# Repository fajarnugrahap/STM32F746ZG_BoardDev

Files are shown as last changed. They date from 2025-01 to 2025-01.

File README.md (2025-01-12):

# STM32F746ZG_Minimum-System
There are some embedded features in this minimum system like UART, I2C, CAN Bus, QuadSPI Flash, Ext. SDRAM, SPI for LCD TFT/Oled Support, USB-C and GPIO port                                              
WhatsApp Image 2024-07-21 at 20 56 39_34f741bc

First thing first I set the pinout configuration of STM32F746ZG by using CubeMx tools in STM32CubeIDE
                                                          
I'm using KiCadV6+ to design this minimum system. There is some additional component to support some peripheral/bus. You can check the component library folder.
f746zg
f746zg(1)
f746zg(3)

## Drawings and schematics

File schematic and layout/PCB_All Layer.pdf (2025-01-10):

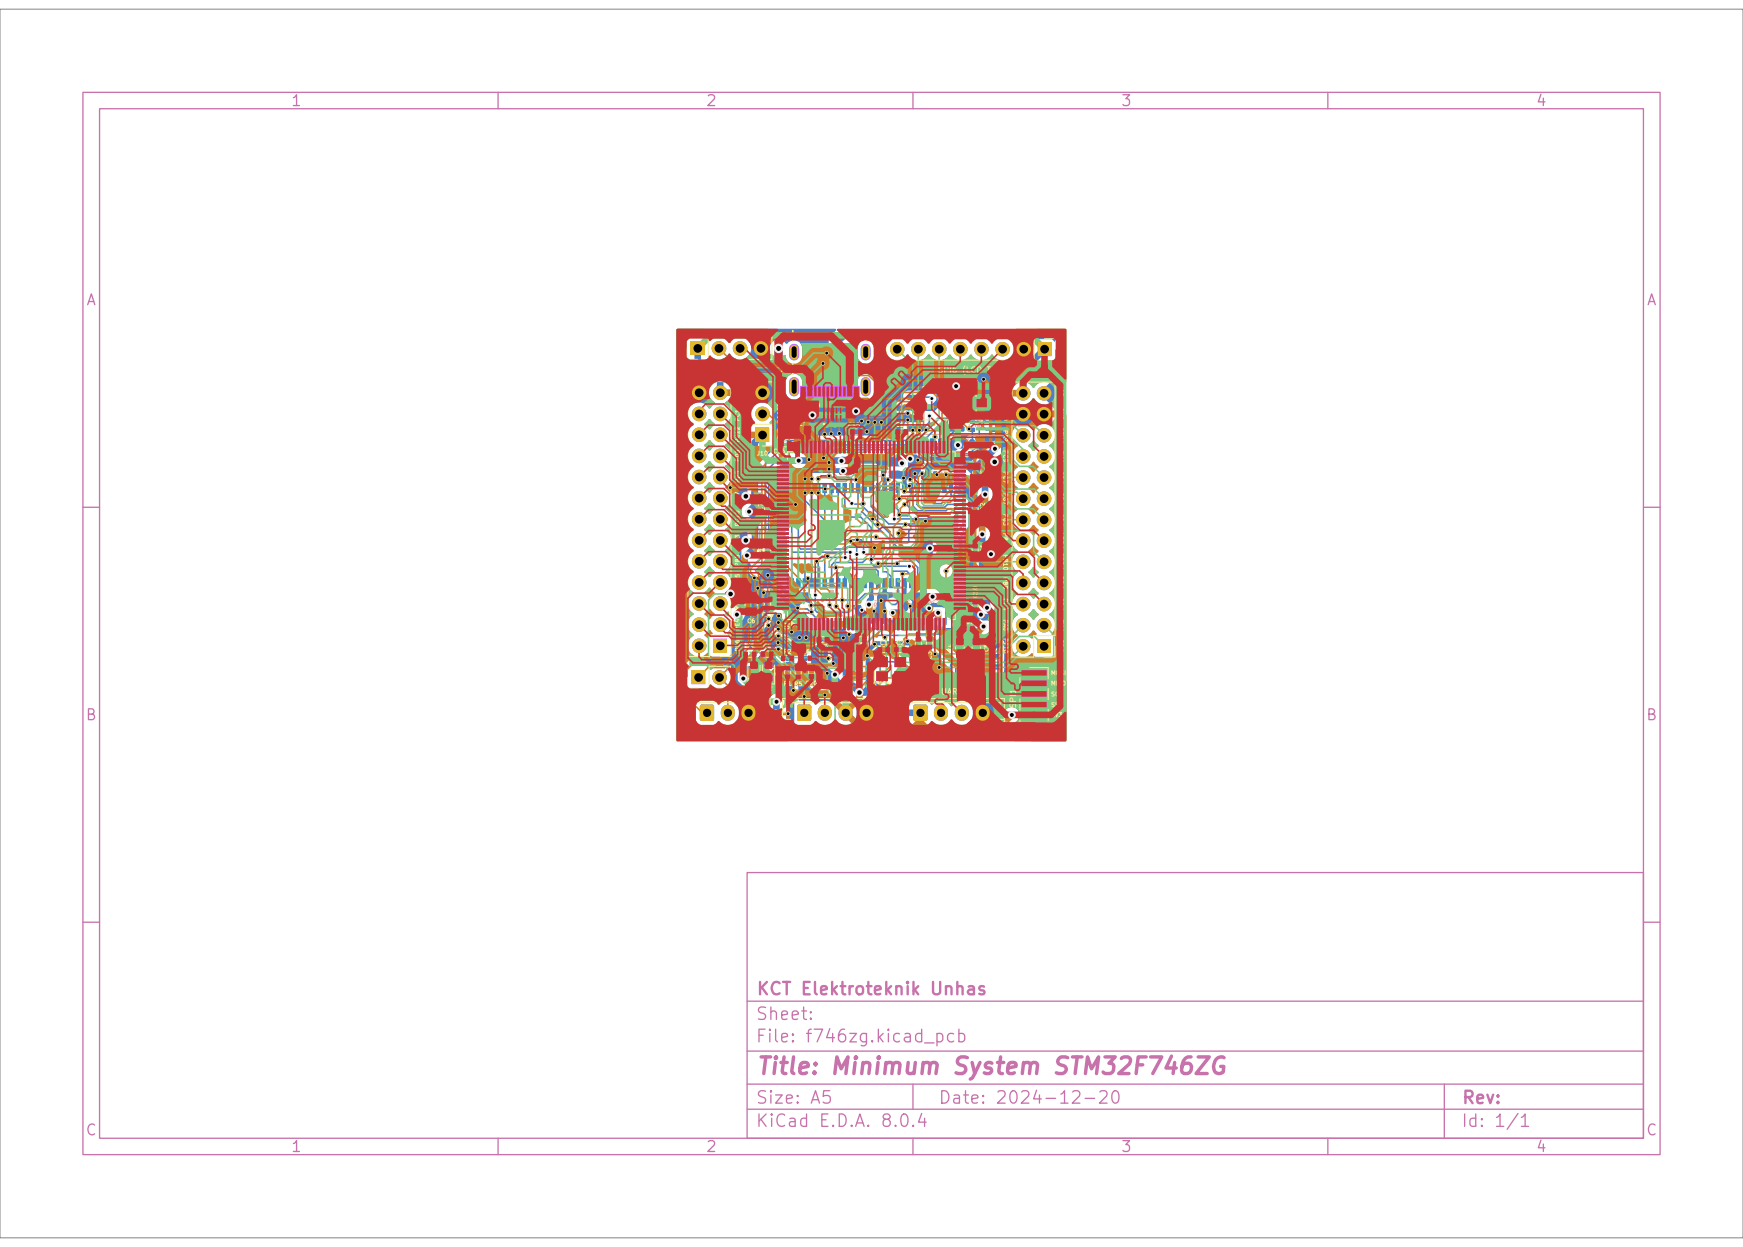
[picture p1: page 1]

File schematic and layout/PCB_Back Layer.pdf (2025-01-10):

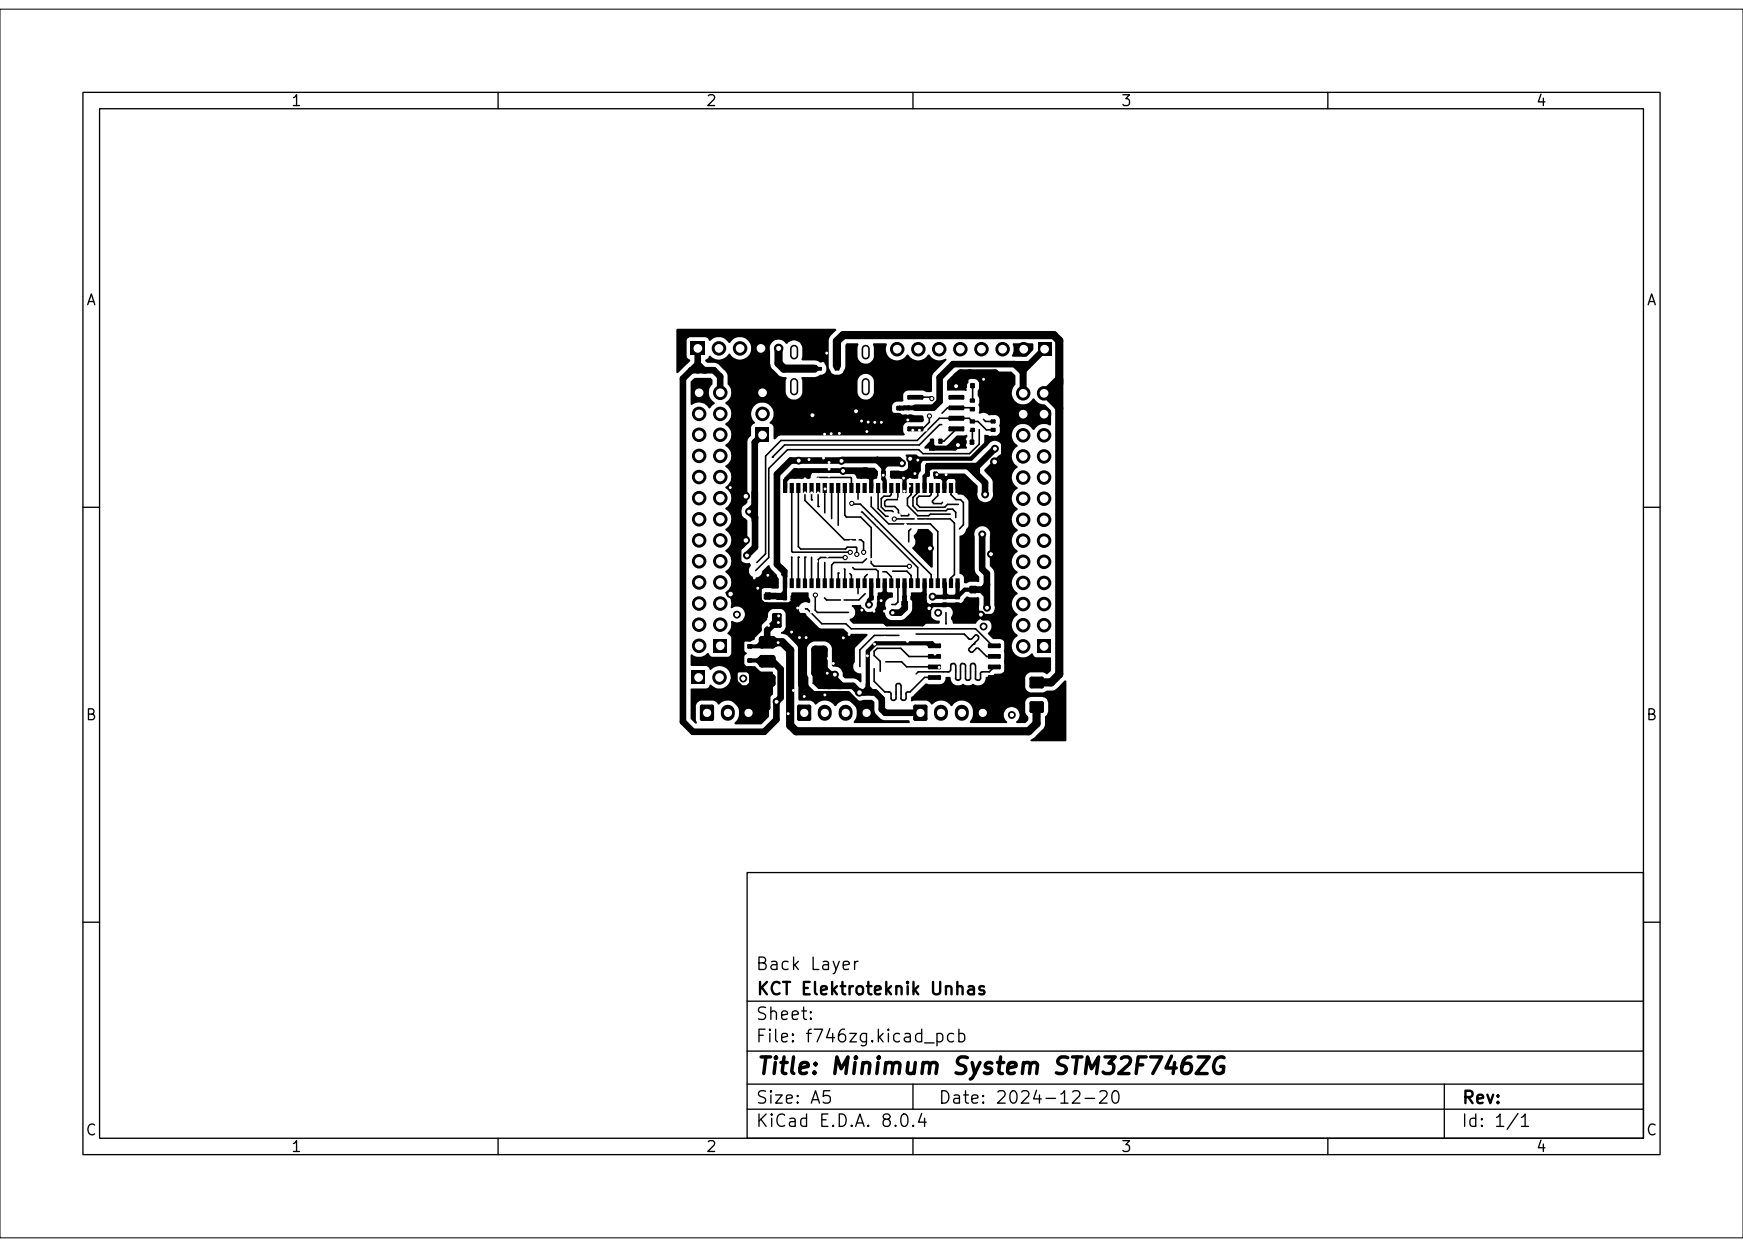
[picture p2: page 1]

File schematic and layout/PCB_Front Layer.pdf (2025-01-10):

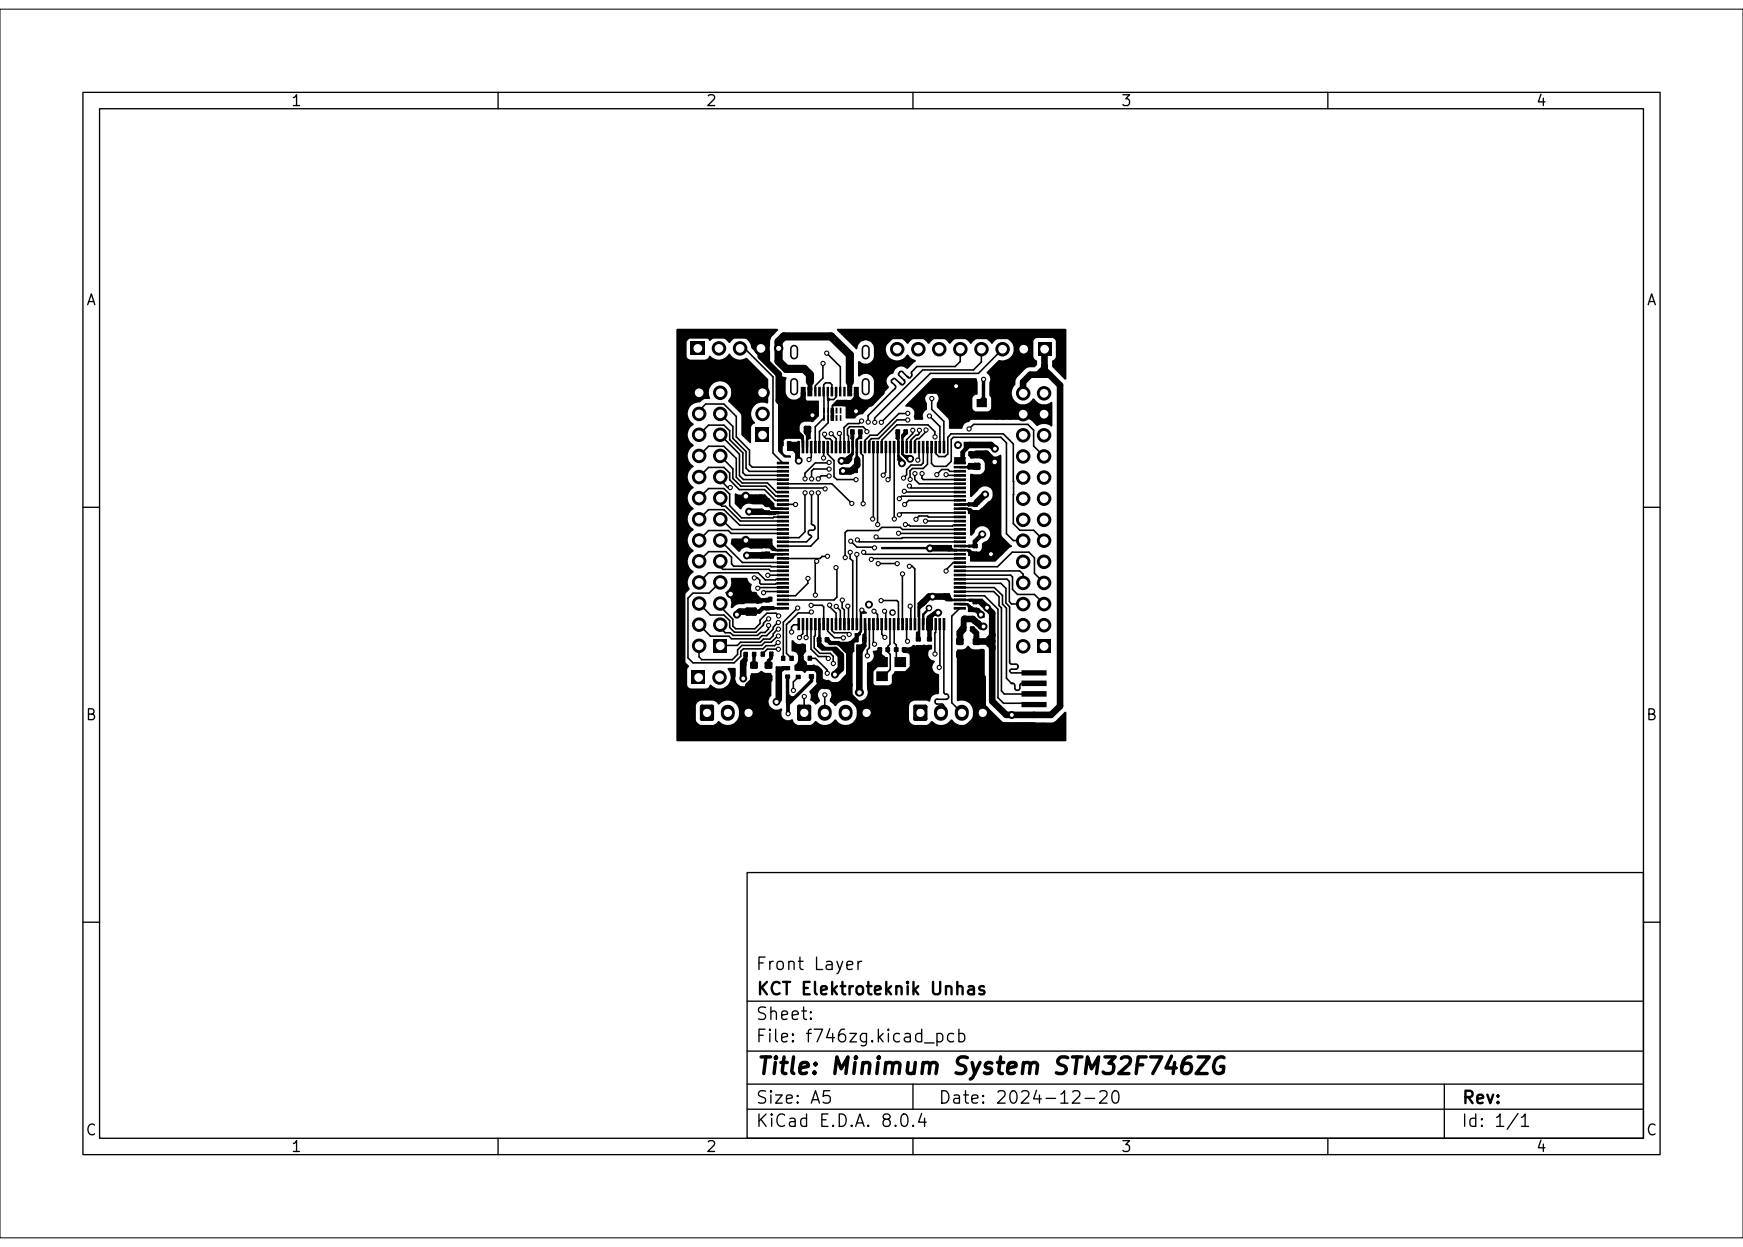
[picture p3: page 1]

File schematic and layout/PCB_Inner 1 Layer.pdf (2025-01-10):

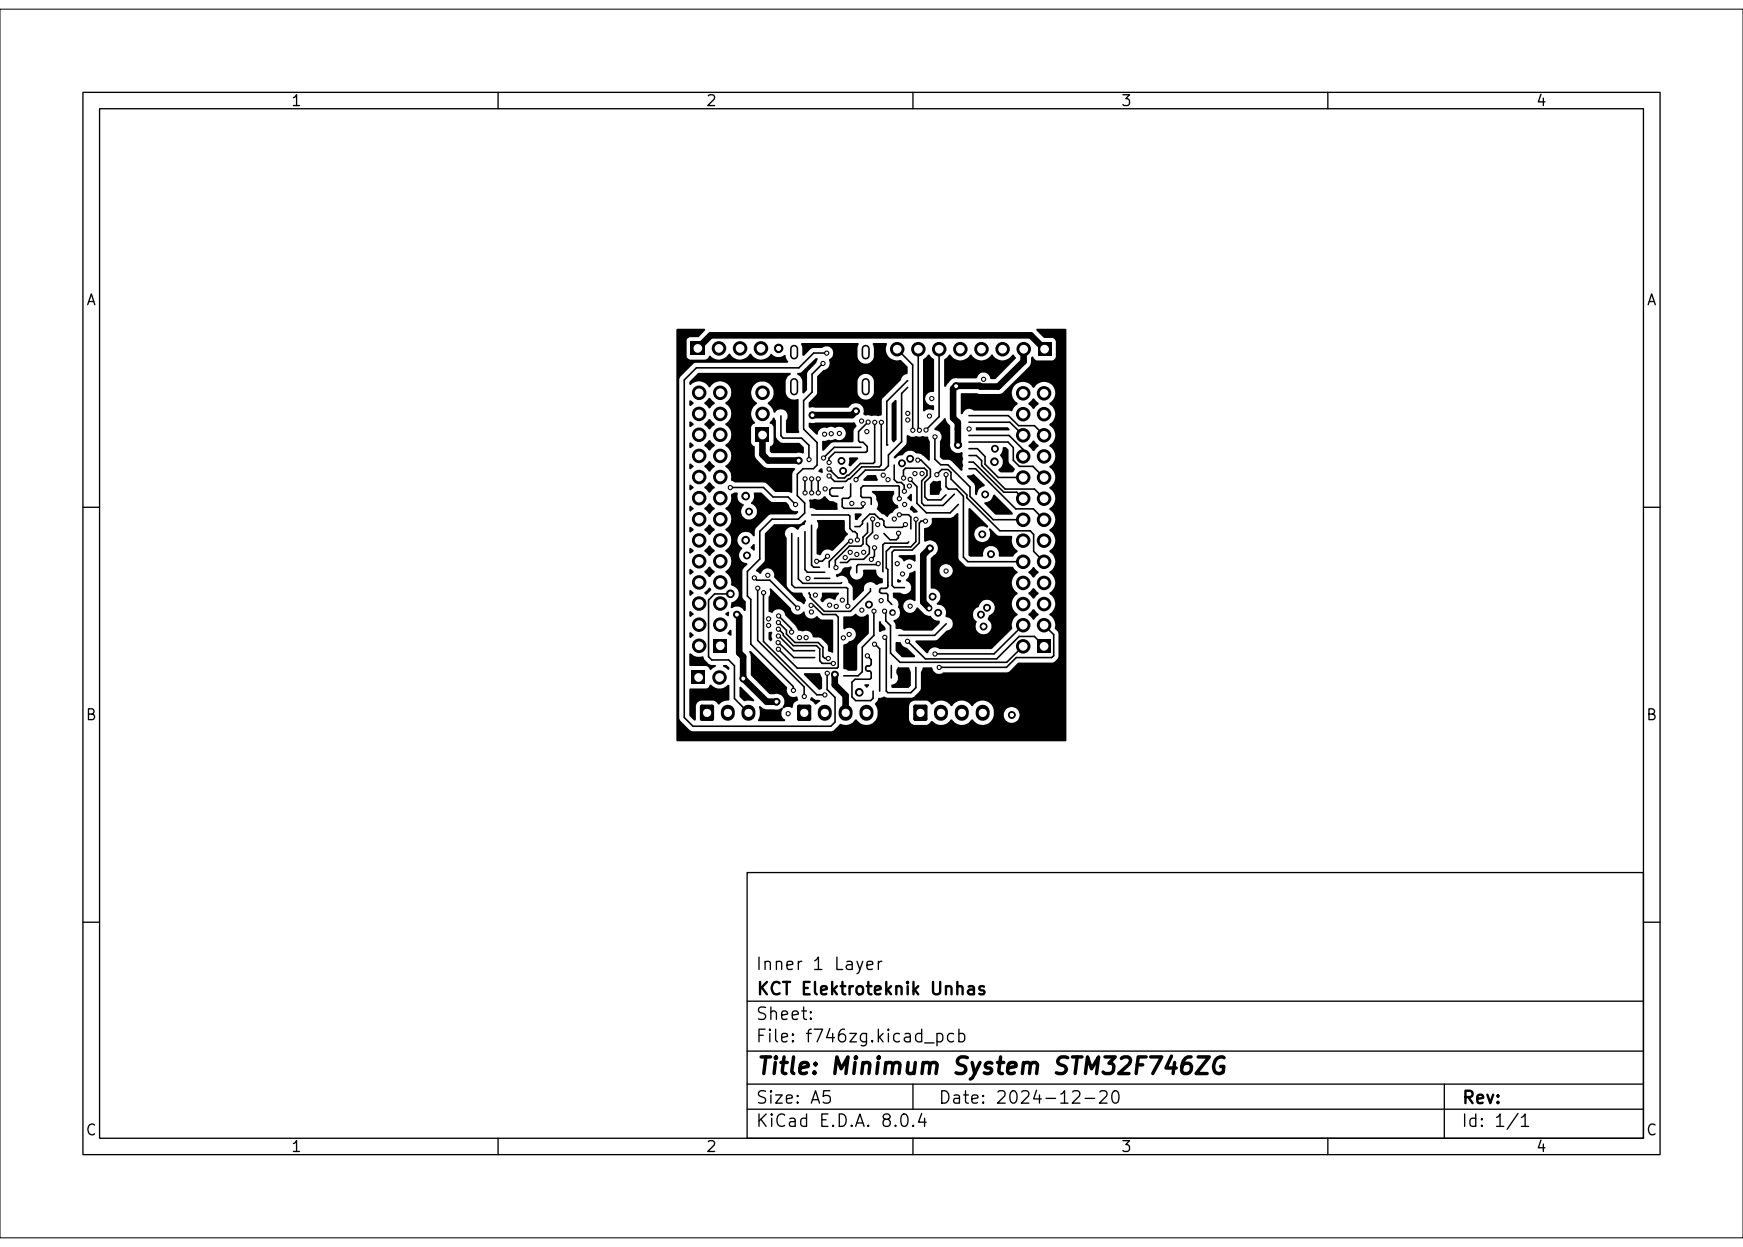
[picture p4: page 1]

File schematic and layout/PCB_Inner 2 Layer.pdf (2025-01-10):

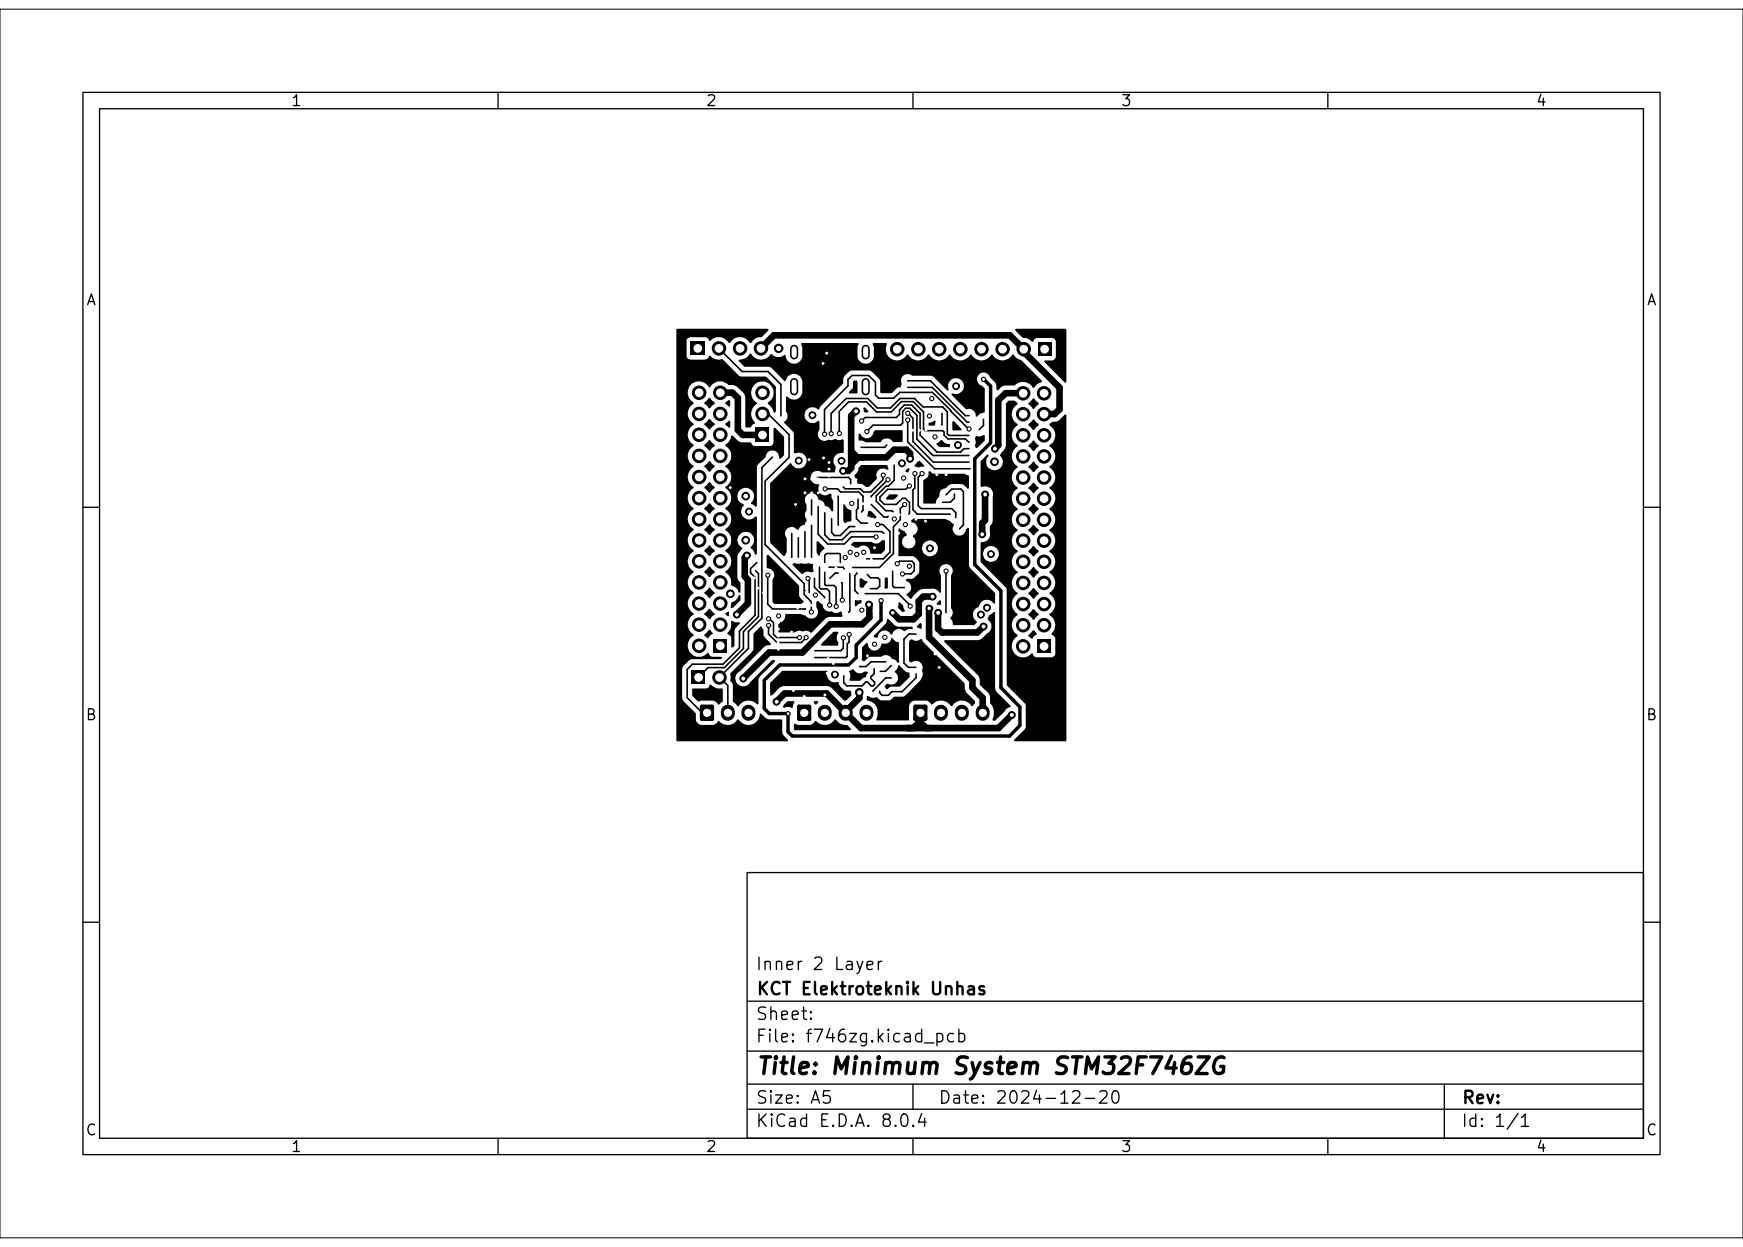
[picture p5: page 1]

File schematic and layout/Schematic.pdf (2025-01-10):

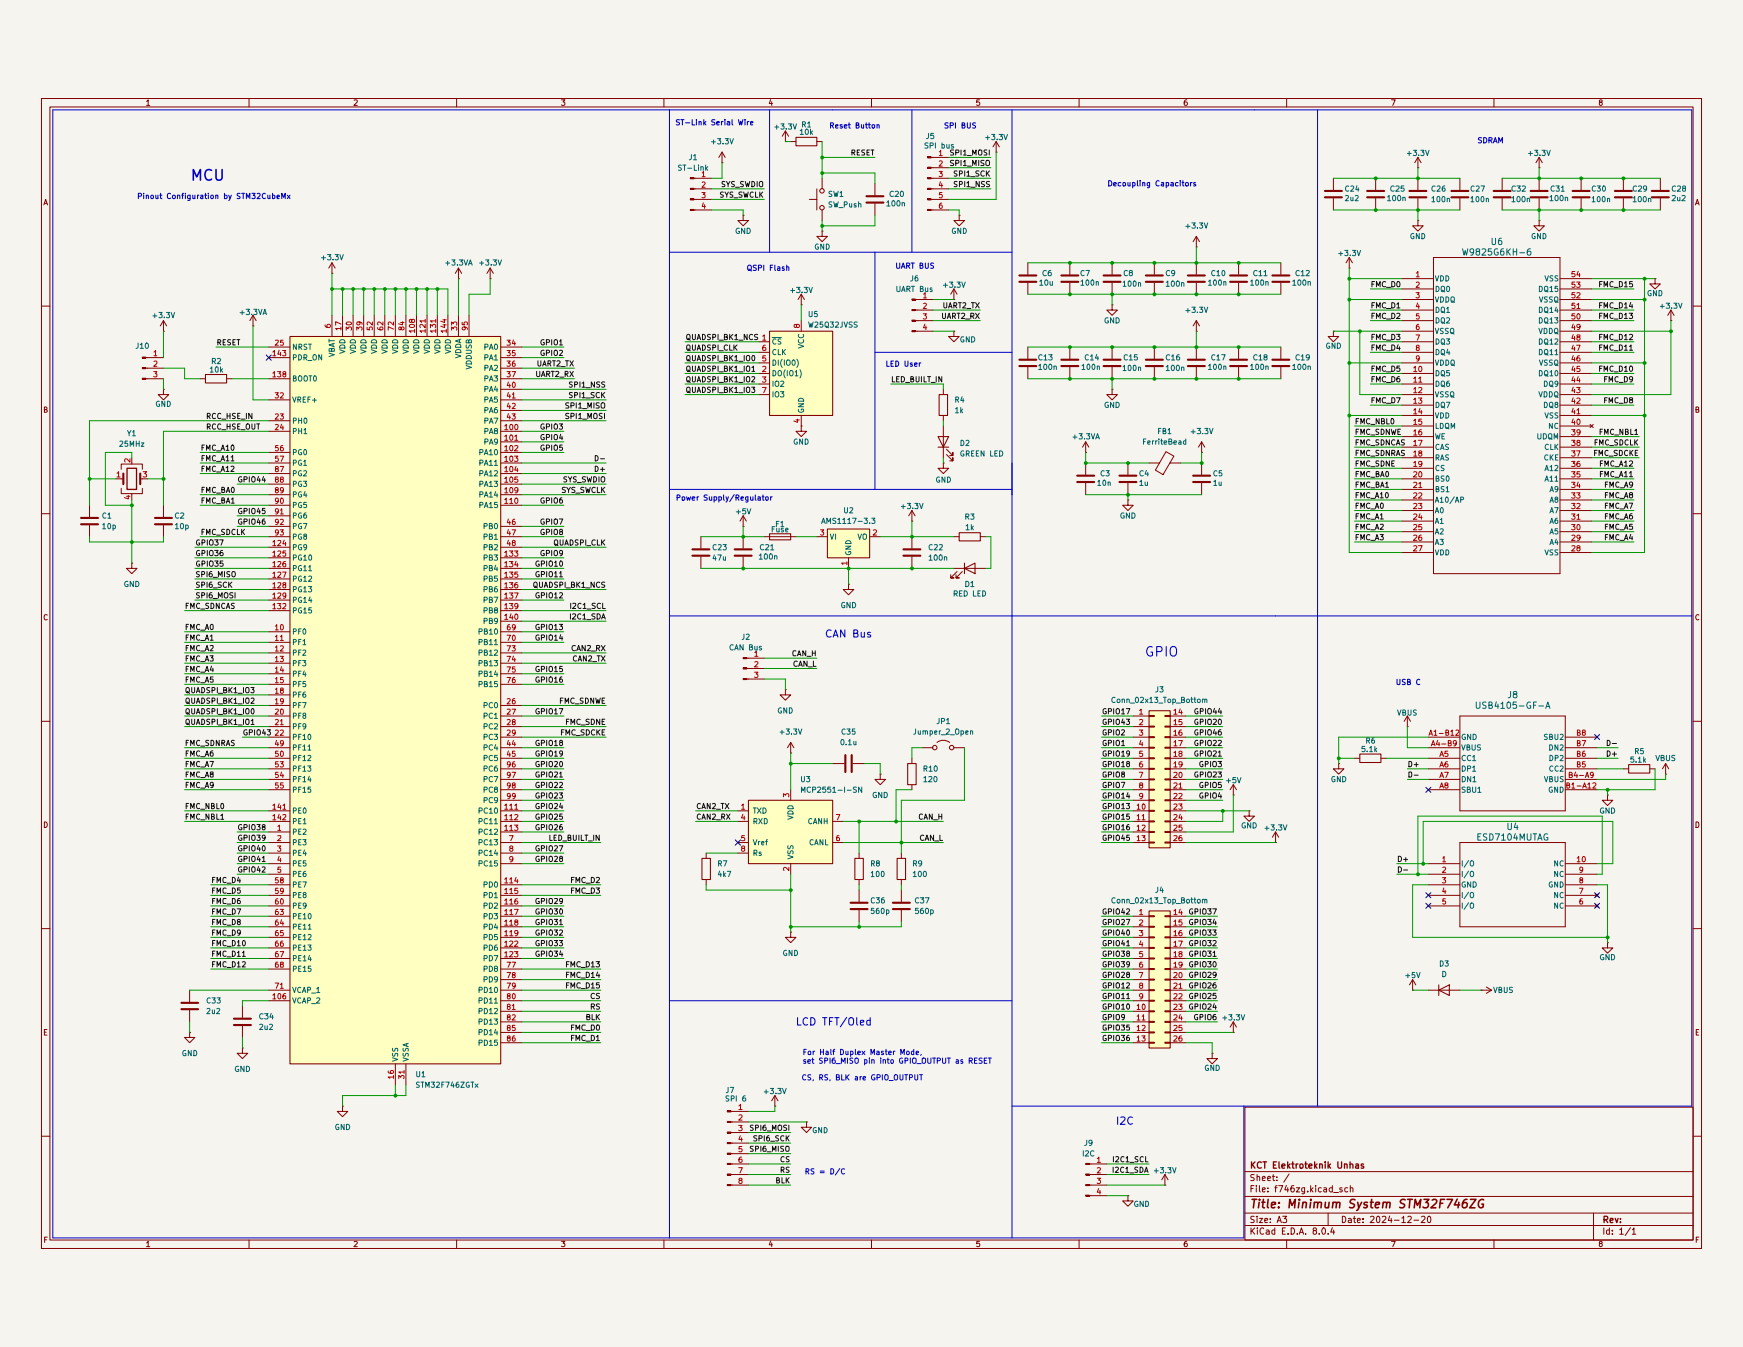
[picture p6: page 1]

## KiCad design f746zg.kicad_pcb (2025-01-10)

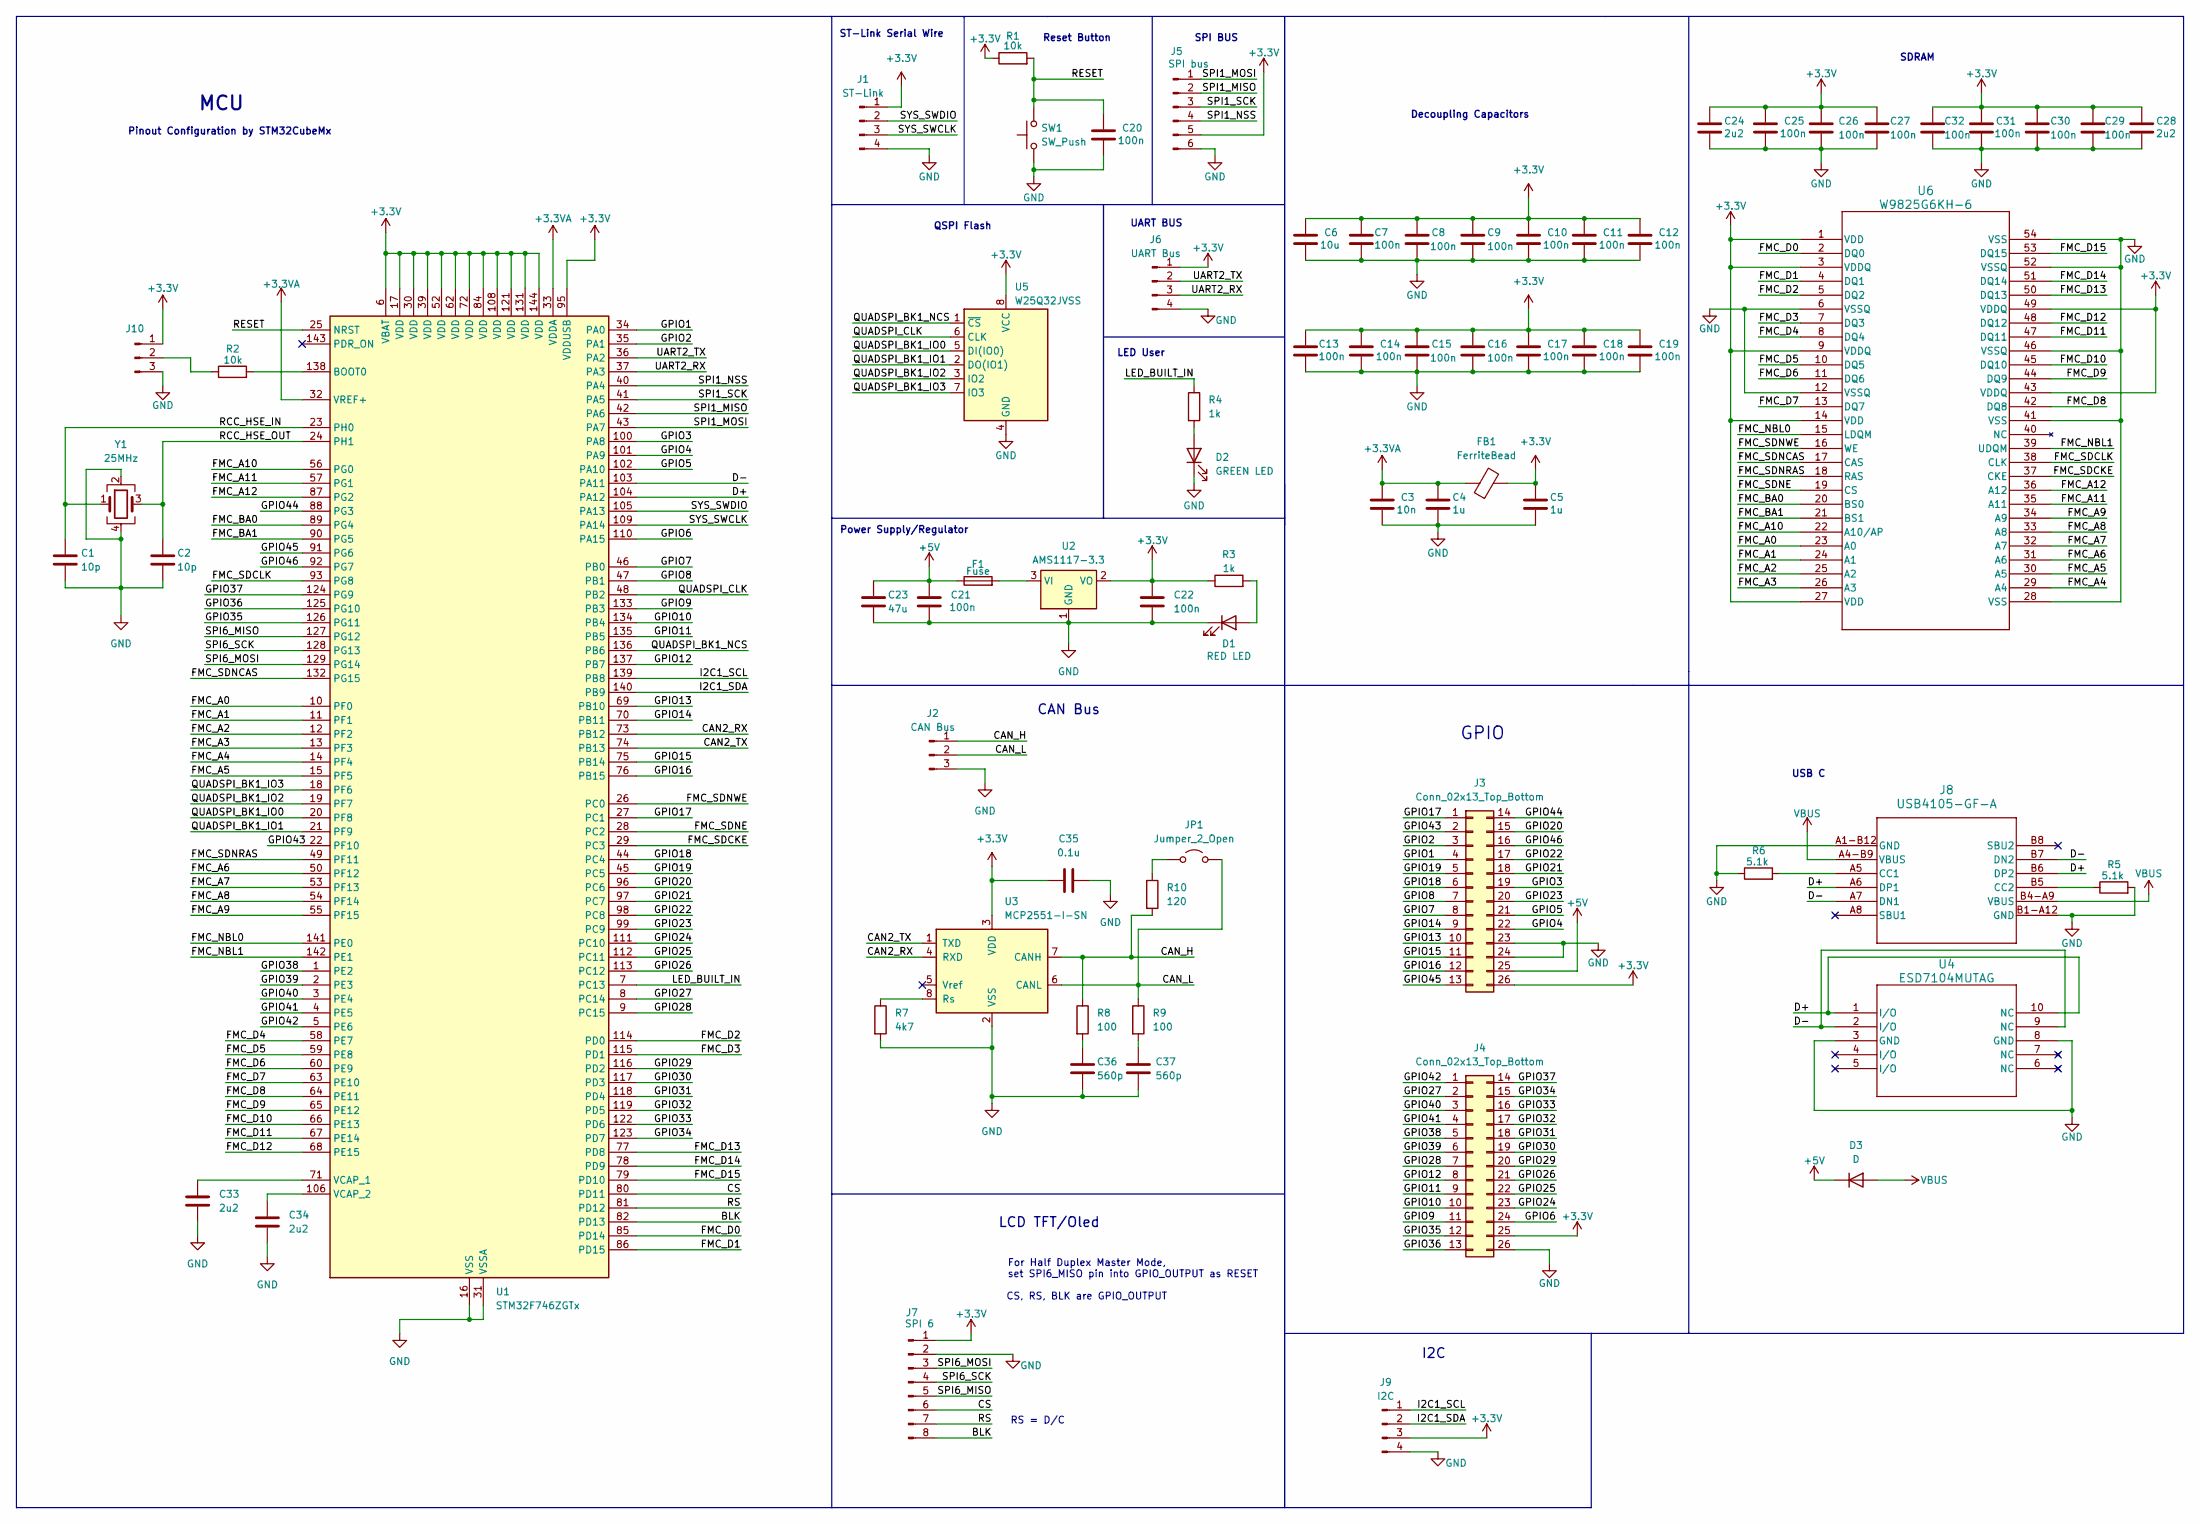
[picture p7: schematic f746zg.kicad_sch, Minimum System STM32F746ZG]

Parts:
C1, C2: 10p; C_0402_1005Metric
C3: 10n; C_0402_1005Metric
C4, C5: 1u; C_0603_1608Metric
C6: 10u; C_0805_2012Metric
C7, C8, C9, C10, C11, C12, C13, C14, C15, C16, C17, C18, C19, C20, C21, C22, C25, C26, C27, C29, C30, C31, C32: 100n; C_0402_1005Metric
C23: 47u; C_1206_3216Metric
C24, C28, C33, C34: 2u2; C_0603_1608Metric
C35: 0.1u; C_0402_1005Metric
C36, C37: 560p; C_0402_1005Metric
D1: RED LED; LED_0603_1608Metric
D2: GREEN LED; LED_0603_1608Metric
D3: D; D_SOD-323
F1: Fuse; Fuse_1206_3216Metric_Pad1.42x1.75mm_HandSolder
FB1: FerriteBead; L_0402_1005Metric
J1: ST-Link; PinHeader_1x04_P2.54mm_Vertical
J2: CAN Bus; JST_EH_B3B-EH-A_1x03_P2.50mm_Vertical
J3, J4: Conn_02x13_Top_Bottom; PinHeader_2x13_P2.54mm_Vertical
J5: SPI bus; PinHeader_1x06_P1.27mm_Vertical_SMD_Pin1Left
J6: UART Bus; JST_EH_B4B-EH-A_1x04_P2.50mm_Vertical
J7: SPI 6; PinHeader_1x08_P2.54mm_Vertical
J8: USB4105-GF-A; GCT_USB4105-GF-A
J9: I2C; JST_EH_B4B-EH-A_1x04_P2.50mm_Vertical
J10: Conn_01x03_Pin; PinHeader_1x03_P2.54mm_Vertical
JP1: Jumper_2_Open; PinHeader_1x02_P2.54mm_Vertical
R1, R2: 10k; R_0402_1005Metric
R3, R4: 1k; R_0402_1005Metric
R5, R6: 5.1k; R_0402_1005Metric
R7: 4k7; R_0402_1005Metric
R8, R9: 100; R_0402_1005Metric
R10: 120; R_0402_1005Metric
SW1: SW_Push; SW_Tactile_SPST_NO_Straight_CK_PTS636Sx25SMTRLFS
U1: STM32F746ZGTx; LQFP-144_20x20mm_P0.5mm
U2: AMS1117-3.3; SOT-223-3_TabPin2
U3: MCP2551-I-SN; SOIC-8_3.9x4.9mm_P1.27mm
U4: ESD7104MUTAG; UDFN10_ONS
U5: W25Q32JVSS; SOIC-8_5.23x5.23mm_P1.27mm
U6: W9825G6KH-6; SMT_5G6KH-6_WIN
Y1: 25MHz; Crystal_SMD_3225-4Pin_3.2x2.5mm

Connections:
+3.3V: C5.1, C6.1, C7.1, C8.1, C9.1, C10.1, C11.1, C12.1, C13.1, C14.1, C15.1, C16.1, C17.1, C18.1, C19.1, C22.1, C24.1, C25.1, C26.2, C27.2, C28.1, C29.2, C30.2, C31.1, C32.2, C35.1, FB1.2, J1.1, J3.26, J4.25, J5.5, J6.1, J7.1, J9.3, J10.1, R1.1, R3.1, U1.6 (VBAT), U1.17 (VDD), U1.30 (VDD), U1.39 (VDD), U1.52 (VDD), U1.62 (VDD), U1.72 (VDD), U1.84 (VDD), U1.95 (VDDUSB), U1.108 (VDD), U1.121 (VDD), U1.131 (VDD), U1.144 (VDD), U2.2 (VO), U3.3 (VDD), U5.8 (VCC), U6.1 (VDD), U6.3 (VDDQ), U6.9 (VDDQ), U6.14 (VDD), U6.27 (VDD), U6.43 (VDDQ), U6.49 (VDDQ)
+3.3VA: C3.1, C4.1, FB1.1, U1.32 (VREF+), U1.33 (VDDA)
/BLK: J7.8, U1.82 (PD13)
/CAN2_RX: U1.73 (PB12), U3.4 (RXD)
/CAN2_TX: U1.74 (PB13), U3.1 (TXD)
/CAN_H: J2.1, R8.1, R10.2, U3.7 (CANH)
/CAN_L: J2.2, JP1.2 (B), R9.1, U3.6 (CANL)
/CS: J7.6, U1.80 (PD11)
/D+: J8.A6 (DP1), J8.B6 (DP2), U1.104 (PA12), U4.1 (I/O), U4.10 (NC)
/D-: J8.A7 (DN1), J8.B7 (DN2), U1.103 (PA11), U4.2 (I/O), U4.9 (NC)
/FMC_A0: U1.10 (PF0), U6.23 (A0)
/FMC_A1: U1.11 (PF1), U6.24 (A1)
/FMC_A2: U1.12 (PF2), U6.25 (A2)
/FMC_A3: U1.13 (PF3), U6.26 (A3)
/FMC_A4: U1.14 (PF4), U6.29 (A4)
/FMC_A5: U1.15 (PF5), U6.30 (A5)
/FMC_A6: U1.50 (PF12), U6.31 (A6)
/FMC_A7: U1.53 (PF13), U6.32 (A7)
/FMC_A8: U1.54 (PF14), U6.33 (A8)
/FMC_A9: U1.55 (PF15), U6.34 (A9)
/FMC_A10: U1.56 (PG0), U6.22 (A10/AP)
/FMC_A11: U1.57 (PG1), U6.35 (A11)
/FMC_A12: U1.87 (PG2), U6.36 (A12)
/FMC_BA0: U1.89 (PG4), U6.20 (BS0)
/FMC_BA1: U1.90 (PG5), U6.21 (BS1)
/FMC_D0: U1.85 (PD14), U6.2 (DQ0)
/FMC_D1: U1.86 (PD15), U6.4 (DQ1)
/FMC_D2: U1.114 (PD0), U6.5 (DQ2)
/FMC_D3: U1.115 (PD1), U6.7 (DQ3)
/FMC_D4: U1.58 (PE7), U6.8 (DQ4)
/FMC_D5: U1.59 (PE8), U6.10 (DQ5)
/FMC_D6: U1.60 (PE9), U6.11 (DQ6)
/FMC_D7: U1.63 (PE10), U6.13 (DQ7)
/FMC_D8: U1.64 (PE11), U6.42 (DQ8)
/FMC_D9: U1.65 (PE12), U6.44 (DQ9)
/FMC_D10: U1.66 (PE13), U6.45 (DQ10)
/FMC_D11: U1.67 (PE14), U6.47 (DQ11)
/FMC_D12: U1.68 (PE15), U6.48 (DQ12)
/FMC_D13: U1.77 (PD8), U6.50 (DQ13)
/FMC_D14: U1.78 (PD9), U6.51 (DQ14)
/FMC_D15: U1.79 (PD10), U6.53 (DQ15)
/FMC_NBL0: U1.141 (PE0), U6.15 (LDQM)
/FMC_NBL1: U1.142 (PE1), U6.39 (UDQM)
/FMC_SDCKE: U1.29 (PC3), U6.37 (CKE)
/FMC_SDCLK: U1.93 (PG8), U6.38 (CLK)
/FMC_SDNCAS: U1.132 (PG15), U6.17 (CAS)
/FMC_SDNE: U1.28 (PC2), U6.19 (CS)
/FMC_SDNRAS: U1.49 (PF11), U6.18 (RAS)
/FMC_SDNWE: U1.26 (PC0), U6.16 (WE)
/GPIO1: J3.4, U1.34 (PA0)
/GPIO2: J3.3, U1.35 (PA1)
/GPIO3: J3.19, U1.100 (PA8)
/GPIO4: J3.22, U1.101 (PA9)
/GPIO5: J3.21, U1.102 (PA10)
/GPIO6: J4.24, U1.110 (PA15)
/GPIO7: J3.8, U1.46 (PB0)
/GPIO8: J3.7, U1.47 (PB1)
/GPIO9: J4.11, U1.133 (PB3)
/GPIO10: J4.10, U1.134 (PB4)
/GPIO11: J4.9, U1.135 (PB5)
/GPIO12: J4.8, U1.137 (PB7)
/GPIO13: J3.10, U1.69 (PB10)
/GPIO14: J3.9, U1.70 (PB11)
/GPIO15: J3.11, U1.75 (PB14)
/GPIO16: J3.12, U1.76 (PB15)
/GPIO17: J3.1, U1.27 (PC1)
/GPIO18: J3.6, U1.44 (PC4)
/GPIO19: J3.5, U1.45 (PC5)
/GPIO20: J3.15, U1.96 (PC6)
/GPIO21: J3.18, U1.97 (PC7)
/GPIO22: J3.17, U1.98 (PC8)
/GPIO23: J3.20, U1.99 (PC9)
/GPIO24: J4.23, U1.111 (PC10)
/GPIO25: J4.22, U1.112 (PC11)
/GPIO26: J4.21, U1.113 (PC12)
/GPIO27: J4.2, U1.8 (PC14)
/GPIO28: J4.7, U1.9 (PC15)
/GPIO29: J4.20, U1.116 (PD2)
/GPIO30: J4.19, U1.117 (PD3)
/GPIO31: J4.18, U1.118 (PD4)
/GPIO32: J4.17, U1.119 (PD5)
/GPIO33: J4.16, U1.122 (PD6)
/GPIO34: J4.15, U1.123 (PD7)
/GPIO35: J4.12, U1.126 (PG11)
/GPIO36: J4.13, U1.125 (PG10)
/GPIO37: J4.14, U1.124 (PG9)
/GPIO38: J4.5, U1.1 (PE2)
/GPIO39: J4.6, U1.2 (PE3)
/GPIO40: J4.3, U1.3 (PE4)
/GPIO41: J4.4, U1.4 (PE5)
/GPIO42: J4.1, U1.5 (PE6)
/GPIO43: J3.2, U1.22 (PF10)
/GPIO44: J3.14, U1.88 (PG3)
/GPIO45: J3.13, U1.91 (PG6)
/GPIO46: J3.16, U1.92 (PG7)
/I2C1_SCL: J9.1, U1.139 (PB8)
/I2C1_SDA: J9.2, U1.140 (PB9)
/LED_BUILT_IN: R4.1, U1.7 (PC13)
/QUADSPI_BK1_IO0: U1.20 (PF8), U5.5 (DI(IO0))
/QUADSPI_BK1_IO1: U1.21 (PF9), U5.2 (DO(IO1))
/QUADSPI_BK1_IO2: U1.19 (PF7), U5.3 (IO2)
/QUADSPI_BK1_IO3: U1.18 (PF6), U5.7 (IO3)
/QUADSPI_BK1_NCS: U1.136 (PB6), U5.1 (~CS)
/QUADSPI_CLK: U1.48 (PB2), U5.6 (CLK)
/RCC_HSE_IN: C1.1, U1.23 (PH0), Y1.1
/RCC_HSE_OUT: C2.1, U1.24 (PH1), Y1.3
/RESET: C20.1, R1.2, SW1.2, U1.25 (NRST)
/RS: J7.7, U1.81 (PD12)
/SPI1_MISO: J5.2, U1.42 (PA6)
/SPI1_MOSI: J5.1, U1.43 (PA7)
/SPI1_NSS: J5.4, U1.40 (PA4)
/SPI1_SCK: J5.3, U1.41 (PA5)
/SPI6_MISO: J7.5, U1.127 (PG12)
/SPI6_MOSI: J7.3, U1.129 (PG14)
/SPI6_SCK: J7.4, U1.128 (PG13)
/SYS_SWCLK: J1.3, U1.109 (PA14)
/SYS_SWDIO: J1.2, U1.105 (PA13)
/UART2_RX: J6.3, U1.37 (PA3)
/UART2_TX: J6.2, U1.36 (PA2)
GND: C1.2, C2.2, C3.2, C4.2, C5.2, C6.2, C7.2, C8.2, C9.2, C10.2, C11.2, C12.2, C13.2, C14.2, C15.2, C16.2, C17.2, C18.2, C19.2, C20.2, C21.2, C22.2, C23.2, C24.2, C25.2, C26.1, C27.1, C28.2, C29.1, C30.1, C31.2, C32.1, C33.2, C34.2, C35.2, C36.1, C37.1, D1.1 (K), D2.1 (K), J1.4, J2.3, J3.23, J3.24, J4.26, J5.6, J6.4, J7.2, J8.A1-B12 (GND), J8.A1_B12, J8.B1-A12 (GND), J8.B1_A12, J9.4, J10.3, R5.2, R6.1, R7.2, SW1.1, U1.16 (VSS), U1.31 (VSSA), U1.38 (VSS), U1.51 (VSS), U1.61 (VSS), U1.83 (VSS), U1.94 (VSS), U1.107 (VSS), U1.120 (VSS), U1.130 (VSS), U2.1 (GND), U3.2 (VSS), U4.3 (GND), U4.8 (GND), U5.4 (GND), U6.6 (VSSQ), U6.12 (VSSQ), U6.28 (VSS), U6.41 (VSS), U6.46 (VSSQ), U6.52 (VSSQ), U6.54 (VSS), Y1.2, Y1.4
unnamed: C36.2, R8.2
unnamed: C37.2, R9.2
unnamed: D1.2 (A), R3.2
unnamed: D2.2 (A), R4.2
unnamed: J8.A5 (CC1), R6.2
unnamed: J8.B5 (CC2), R5.1
unnamed: J10.2, R2.1
unnamed: JP1.1 (A), R10.1
unnamed: R2.2, U1.138 (BOOT0)
unnamed: C33.1, U1.71 (VCAP_1)
unnamed: C34.1, U1.106 (VCAP_2)
unnamed: R7.1, U3.8 (Rs)
VBUS: D3.2 (A), J8.A4-B9 (VBUS), J8.A4_B9, J8.B4-A9 (VBUS), J8.B4_A9

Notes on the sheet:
Decoupling Capacitors
QSPI Flash
LED User
SDRAM
UART BUS
RS = D/C
SPI BUS
USB C
CAN Bus
GPIO
Pinout Configuration by STM32CubeMx
For Half Duplex Master Mode, set SPI6_MISO pin into GPIO_OUTPUT as RESET
CS, RS, BLK are GPIO_OUTPUT
ST-Link Serial Wire
Power Supply/Regulator
I2C
Reset Button
LCD TFT/Oled
MCU

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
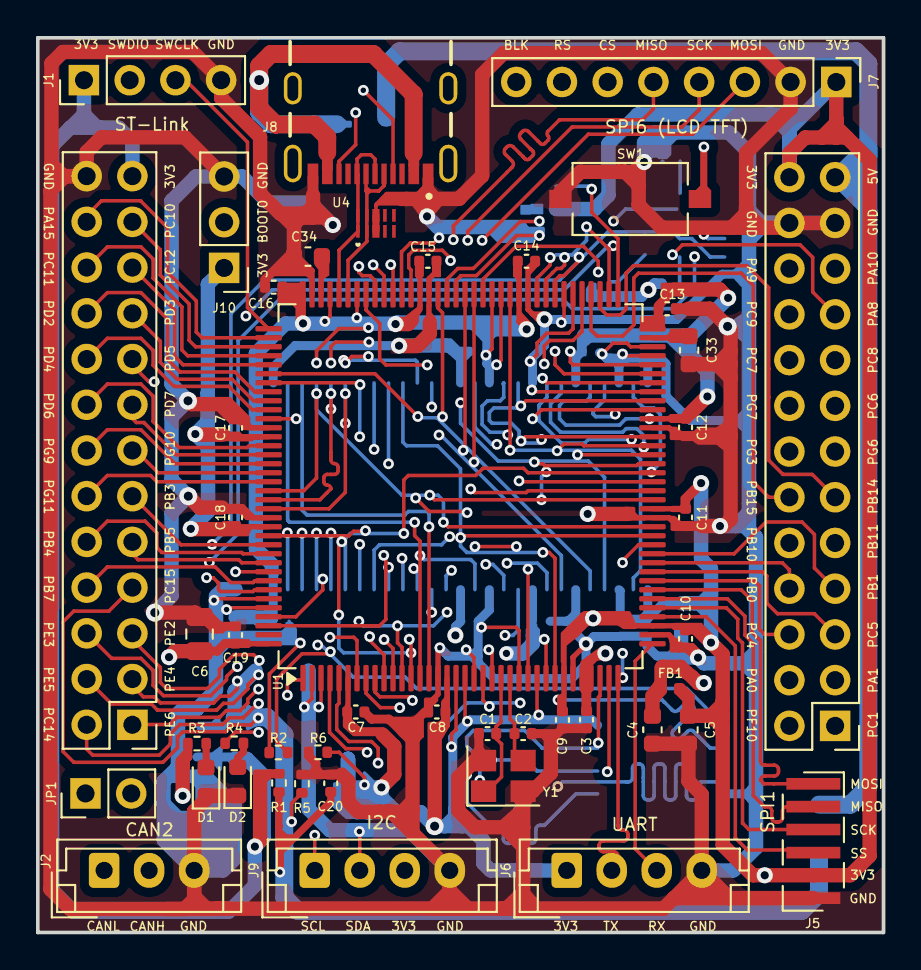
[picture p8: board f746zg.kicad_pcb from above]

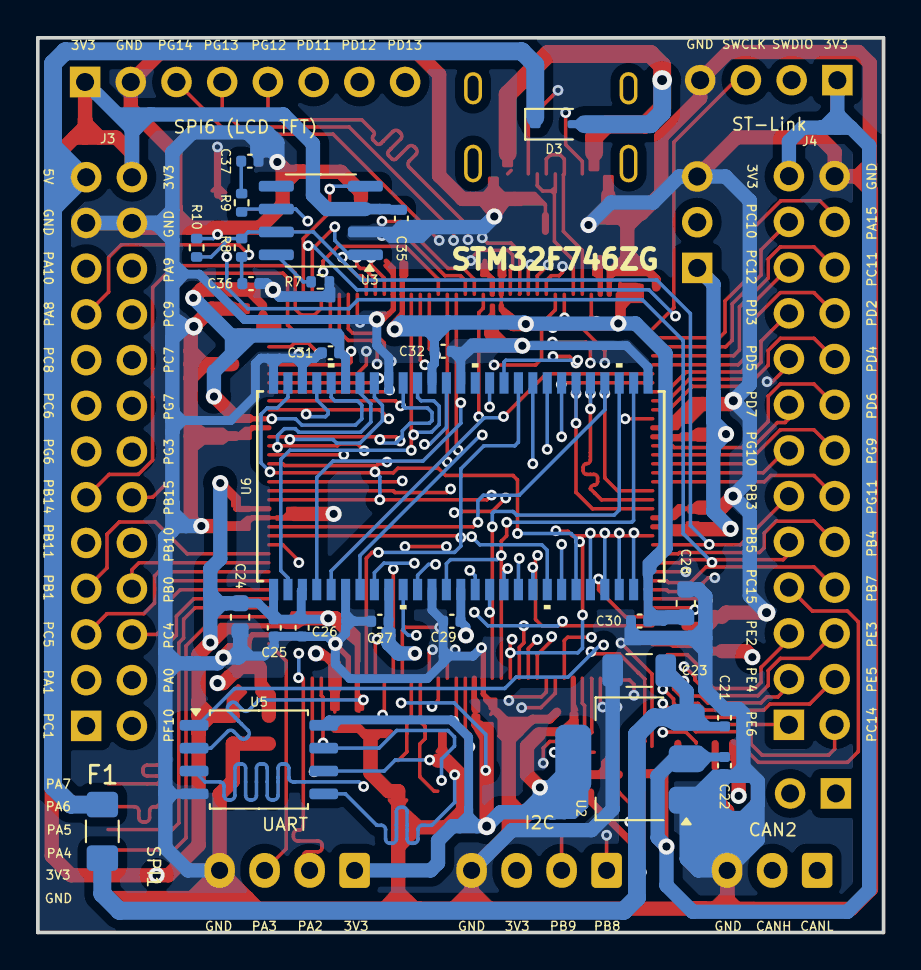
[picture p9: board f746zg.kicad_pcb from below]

Board: 4 copper layers, 47.0 x 49.7 mm, 71 parts (25 on the bottom side), 135 nets.

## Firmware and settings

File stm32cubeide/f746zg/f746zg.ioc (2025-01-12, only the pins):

Mcu.UserName=STM32F746ZGTx
PA0/WKUP.Signal=UART4_TX
PA1.Signal=UART4_RX
PA10.Signal=USB_OTG_FS_ID
PA11.Signal=USB_OTG_FS_DM
PA12.Signal=USB_OTG_FS_DP
PA13.Signal=SYS_JTMS-SWDIO
PA14.Signal=SYS_JTCK-SWCLK
PA4.Signal=SPI1_NSS
PA5.Signal=SPI1_SCK
PA6.Signal=SPI1_MISO
PA8.Signal=USB_OTG_FS_SOF
PA9.Signal=USB_OTG_FS_VBUS
PB12.Signal=CAN2_RX
PB13.Signal=CAN2_TX
PB2.Signal=QUADSPI_CLK
PB5.Signal=SPI1_MOSI
PB6.Signal=QUADSPI_BK1_NCS
PB7.Signal=I2C1_SDA
PB8.Signal=I2C1_SCL
PC0.Signal=FMC_SDNWE
PC13.Signal=GPIO_Output
PC2.Signal=FMC_SDNE0
PC3.Signal=FMC_SDCKE0
PD0.Signal=FMC_D2_DA2
PD1.Signal=FMC_D3_DA3
PD10.Signal=FMC_D15_DA15
PD14.Signal=FMC_D0_DA0
PD15.Signal=FMC_D1_DA1
PD8.Signal=FMC_D13_DA13
PD9.Signal=FMC_D14_DA14
PE0.Signal=FMC_NBL0
PE1.Signal=FMC_NBL1
PE10.Signal=FMC_D7_DA7
PE11.Signal=FMC_D8_DA8
PE12.Signal=FMC_D9_DA9
PE13.Signal=FMC_D10_DA10
PE14.Signal=FMC_D11_DA11
PE15.Signal=FMC_D12_DA12
PE7.Signal=FMC_D4_DA4
PE8.Signal=FMC_D5_DA5
PE9.Signal=FMC_D6_DA6
PF0.Signal=FMC_A0
PF1.Signal=FMC_A1
PF11.Signal=FMC_SDNRAS
PF12.Signal=FMC_A6
PF13.Signal=FMC_A7
PF14.Signal=FMC_A8
PF15.Signal=FMC_A9
PF2.Signal=FMC_A2
PF3.Signal=FMC_A3
PF4.Signal=FMC_A4
PF5.Signal=FMC_A5
PF6.Signal=QUADSPI_BK1_IO3
PF7.Signal=QUADSPI_BK1_IO2
PF8.Signal=QUADSPI_BK1_IO0
PF9.Signal=QUADSPI_BK1_IO1
PG0.Signal=FMC_A10
PG1.Signal=FMC_A11
PG15.Signal=FMC_SDNCAS
PG2.Signal=FMC_A12
PG4.Signal=FMC_A14_BA0
PG5.Signal=FMC_A15_BA1
PG8.Signal=FMC_SDCLK
PH0/OSC_IN.Signal=RCC_OSC_IN
PH1/OSC_OUT.Signal=RCC_OSC_OUT
